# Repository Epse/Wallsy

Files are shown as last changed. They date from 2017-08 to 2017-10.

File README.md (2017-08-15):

# Wallsy
Firmware for a hacked Disney U-Control Wall-e

## What the frig is this?
Me and someone without a github replaced the logic board in a U-Control Wall-e with a [Teensy LC](https://www.pjrc.com/teensy/teensyLC.html).
We added a distance sensor (a Sharp optical ridiculously expensive one since the Chinese ultrasonic cheap ones wouldn't arrive in time)
and a yellow LED in the middle of the sun on Wall-e's 'display'.

## Why would you do that?
It's fun!

## How do I use this?
Get a Teensy, wire it up, modify the `#define`'s in the `main.ino` file and upload to the Teensy.
That is, if your Arduino IDE has the [Teensy libraries](https://www.pjrc.com/teensy/teensyduino.html) installed.

## What works and what doesn't?
- [ ] motor control
- [x] LED blinking
- [ ] IR control
- [ ] Sounds
- [ ] Distance sensing

Yes, for now you let it run by programming moves...

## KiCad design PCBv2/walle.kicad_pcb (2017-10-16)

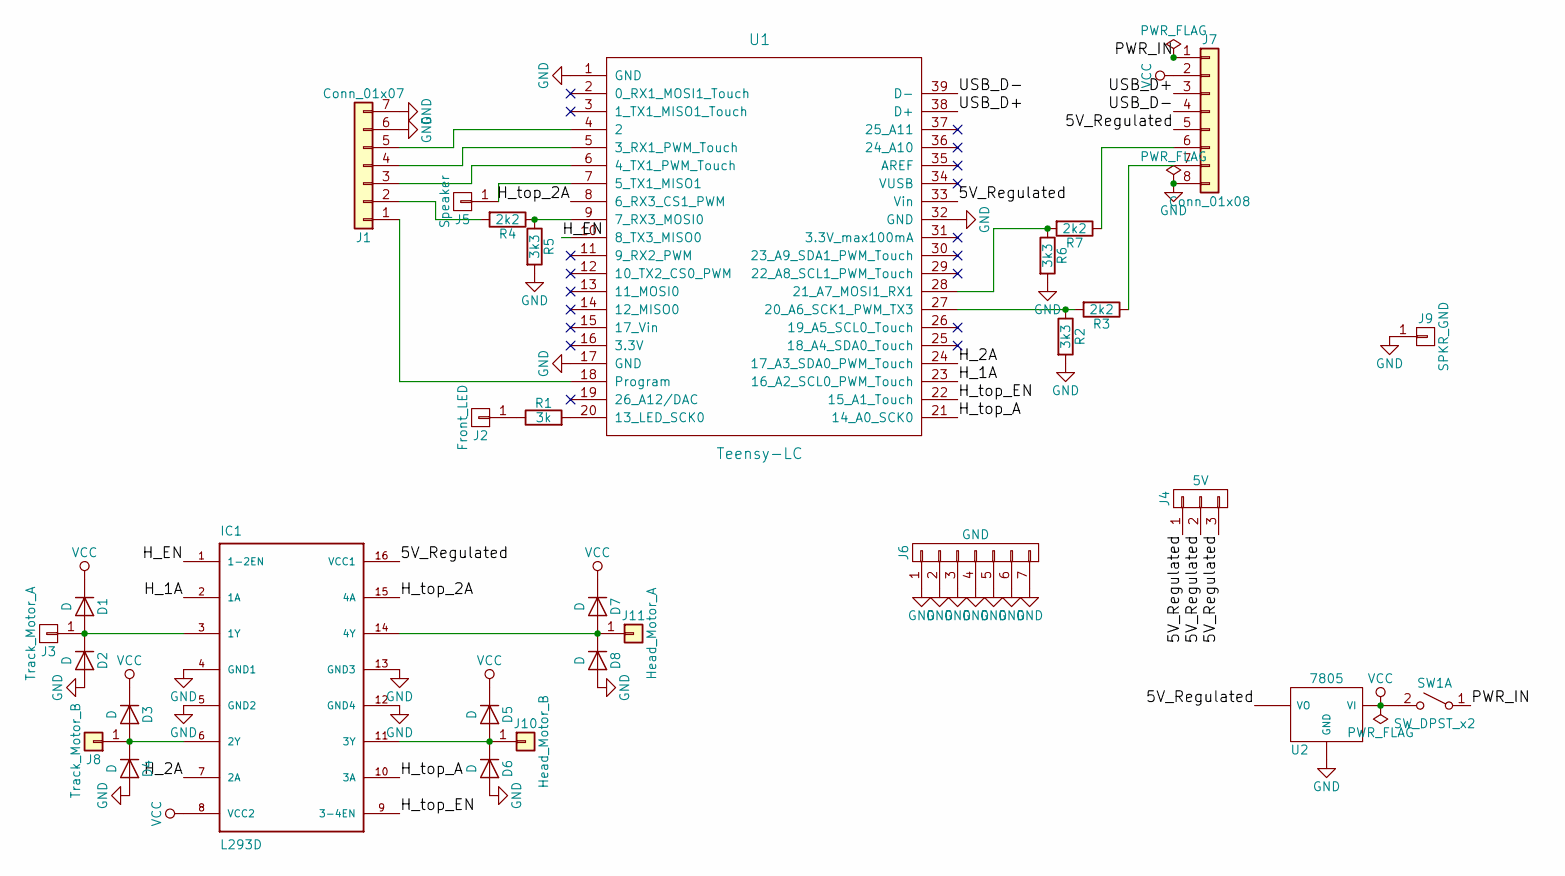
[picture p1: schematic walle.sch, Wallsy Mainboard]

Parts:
D1, D2, D3, D4, D5, D6, D7, D8: D; D_A-405_P2.54mm_Vertical_AnodeUp
IC1: L293D; DIL16
J1: Conn_01x07; Pin_Header_Straight_1x07_Pitch2.54mm
J2: Front_LED; Pin_Header_Straight_1x01_Pitch2.54mm
J3: Track_Motor_A; Pin_Header_Straight_1x01_Pitch2.54mm
J4: 5V; Pin_Header_Straight_1x03_Pitch2.54mm
J5: Speaker; Pin_Header_Straight_1x01_Pitch2.54mm
J6: GND; Pin_Header_Straight_1x07_Pitch2.54mm
J7: Conn_01x08; Pin_Header_Straight_1x08_Pitch2.54mm
J8: Track_Motor_B; Pin_Header_Straight_1x01_Pitch2.54mm
J9: SPKR_GND; Pin_Header_Straight_1x01_Pitch2.54mm
J10: Head_Motor_B; Pin_Header_Straight_1x01_Pitch2.54mm
J11: Head_Motor_A; Pin_Header_Straight_1x01_Pitch2.54mm
R1: 3k; R_Axial_DIN0204_L3.6mm_D1.6mm_P1.90mm_Vertical
R2, R5, R6: 3k3; R_Axial_DIN0204_L3.6mm_D1.6mm_P1.90mm_Vertical
R3, R4, R7: 2k2; R_Axial_DIN0204_L3.6mm_D1.6mm_P1.90mm_Vertical
SW1: SW_DPST_x2; Pin_Header_Straight_1x02_Pitch2.54mm
U1: Teensy-LC; Teensy30_31_32_LC
U2: 7805; TO-220

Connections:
/5V_Regulated: IC1.16 (VCC1), J4.1, J4.2, J4.3, J7.5, U1.33 (Vin), U2.3 (VO)
/H_1A: IC1.2 (1A), U1.23 (16_A2_SCL0_PWM_Touch)
/H_2A: IC1.7 (2A), U1.24 (17_A3_SDA0_PWM_Touch)
/H_EN: IC1.1 (1-2EN), U1.10 (8_TX3_MISO0)
/H_top_2A: IC1.15 (4A), U1.8 (6_RX3_CS1_PWM)
/H_top_A: IC1.10 (3A), U1.21 (14_A0_SCK0)
/H_top_EN: IC1.9 (3-4EN), U1.22 (15_A1_Touch)
/PWR_IN: J7.1, SW1.1 (A)
/USB_D+: J7.3, U1.38 (D+)
/USB_D-: J7.4, U1.39 (D-)
GND: D2.2 (A), D4.2 (A), D6.2 (A), D8.2 (A), IC1.4 (GND1), IC1.5 (GND2), IC1.12 (GND4), IC1.13 (GND3), J1.6, J1.7, J6.1, J6.2, J6.3, J6.4, J6.5, J6.6, J6.7, J7.8, J9.1, R2.2, R5.2, R6.2, U1.1 (GND), U1.17 (GND), U1.32 (GND), U2.2 (GND)
unnamed: D1.2 (A), D2.1 (K), IC1.3 (1Y), J3.1
unnamed: D3.2 (A), D4.1 (K), IC1.6 (2Y), J8.1
unnamed: D5.2 (A), D6.1 (K), IC1.11 (3Y), J10.1
unnamed: D7.2 (A), D8.1 (K), IC1.14 (4Y), J11.1
unnamed: J1.1, U1.18 (Program)
unnamed: J1.2, R4.2
unnamed: J1.3, U1.6 (4_TX1_PWM_Touch)
unnamed: J1.4, U1.5 (3_RX1_PWM_Touch)
unnamed: J1.5, U1.4 (2)
unnamed: J2.1, R1.1
unnamed: J5.1, U1.7 (5_TX1_MISO1)
unnamed: J7.6, R7.1
unnamed: J7.7, R3.1
unnamed: R1.2, U1.20 (13_LED_SCK0)
unnamed: R2.1, R3.2, U1.27 (20_A6_SCK1_PWM_TX3)
unnamed: R4.1, R5.1, U1.9 (7_RX3_MOSI0)
unnamed: R6.1, R7.2, U1.28 (21_A7_MOSI1_RX1)
unnamed: SW1.2 (B), U2.1 (VI)
VCC: D1.1 (K), D3.1 (K), D5.1 (K), D7.1 (K), IC1.8 (VCC2), J7.2

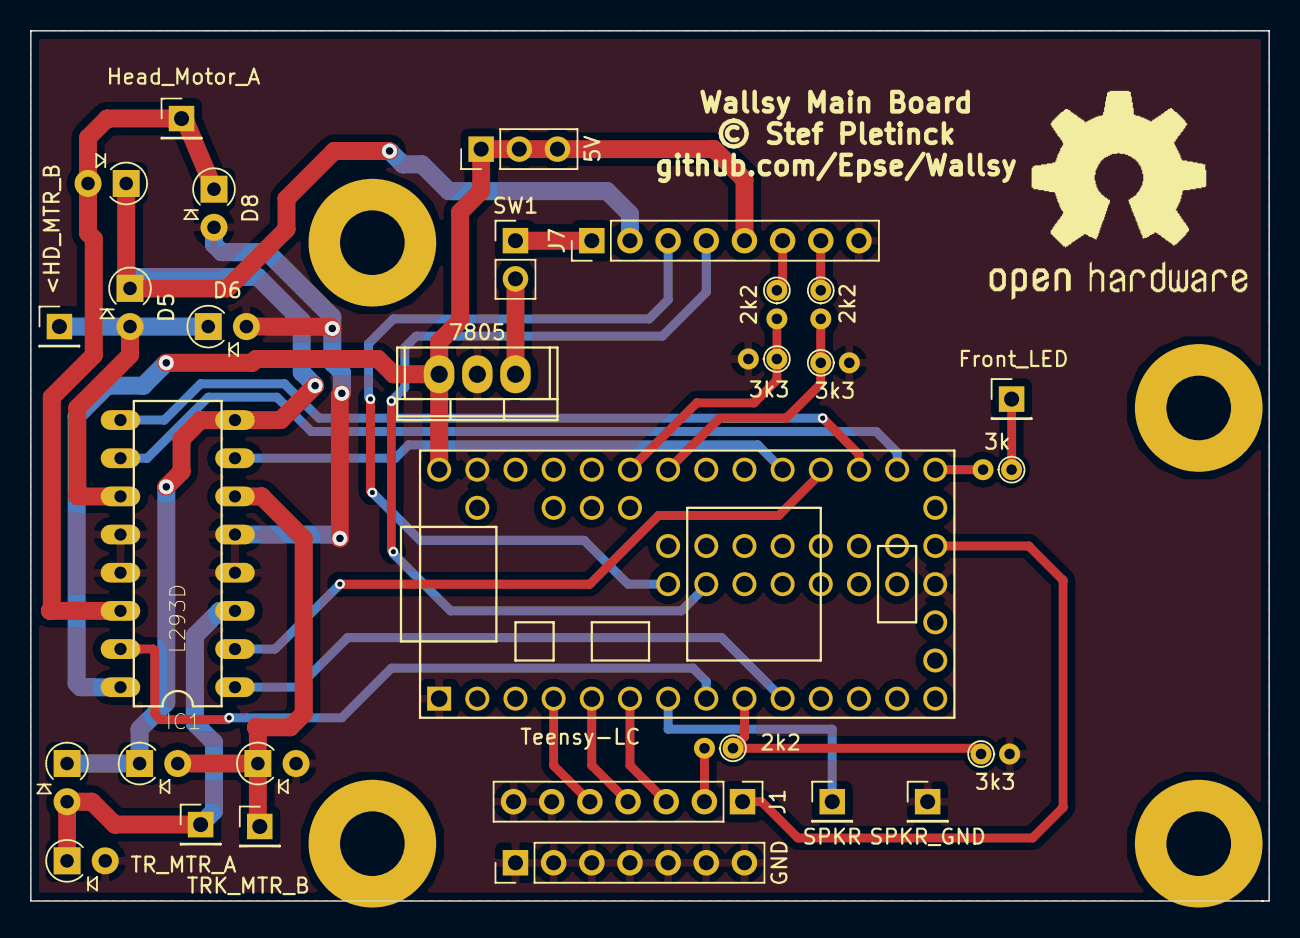
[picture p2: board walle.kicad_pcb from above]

Board: 2 copper layers, 82.4 x 57.9 mm, 30 parts (0 on the bottom side), 30 nets.

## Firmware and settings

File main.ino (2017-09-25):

#include <Arduino.h>
#include "motor.h"
#include "ircodes.h"
#include <IRremote.h>

#define STATUS_LED 13
#define LEFT_EYE_LED 3
#define RIGHT_EYE_LED 4
#define IR_TOP 21
#define IR_REAR 7
#define SPEAKER 5
#define H_BRIDGE_TOP_ENABLE 15
#define H_BRIDGE_TOP_A 14
#define H_BRIDGE_TOP_B 6
#define H_BRIDGE_MVMT_ENABLE 8
#define H_BRIDGE_MVMT_A 17
#define H_BRIDGE_MVMT_B 16
#define DISTANCE_SENS 20

Motor headMotor;
Motor mvmtMotor;

IRrecv irrecvRear(IR_REAR);

unsigned long lastTickMillis = 0;
unsigned long last5Millis = 0;
unsigned long last10Millis = 0;
unsigned long last500Millis = 0;
boolean statusLedValue = LOW;
boolean frontBtnLastKnownValue = false;

void setup() {
  Serial.begin(9600);

  // All my outputs. Tons!!!
  pinMode(STATUS_LED, OUTPUT);
  pinMode(LEFT_EYE_LED, OUTPUT);
  pinMode(RIGHT_EYE_LED, OUTPUT);
  pinMode(SPEAKER, OUTPUT);
  pinMode(DISTANCE_SENS, INPUT);

  // Inputs. Wayyyy less.
  pinMode(IR_TOP, INPUT);
  pinMode(IR_REAR, INPUT);

  irrecvRear.enableIRIn();
  irrecvRear.blink13(true);

  // Own libraries
  // This also initializes the necessary pins to output.
  headMotor.init(H_BRIDGE_TOP_ENABLE, H_BRIDGE_TOP_A, H_BRIDGE_TOP_B);
  mvmtMotor.init(H_BRIDGE_MVMT_ENABLE, H_BRIDGE_MVMT_A, H_BRIDGE_MVMT_B);
  mvmtMotor.enable();

  // Set up some eyes
  analogWrite(LEFT_EYE_LED, 128);
  analogWrite(RIGHT_EYE_LED, 128);
}

// Is called as fast as possible with the delta the millisecond difference since last call.
// WARNING: the delta can be 0!
void tickDispatch(unsigned long delta) {
  lastTickMillis = millis();

  boolean motorShouldTurn = false;
  boolean eyesShouldLight = false;

  decode_results results;
  if (irrecvRear.decode(&results)) {
    if (results.value == IRR_Turn) {
      mvmtMotor.backwards();
      motorShouldTurn = true;
    }

    if (results.value == IRR_Forwards) {
      mvmtMotor.forwards();
      motorShouldTurn = true;
    }

    if (results.value == IRR_Eyes) {
      analogWrite(LEFT_EYE_LED, 400);
      analogWrite(RIGHT_EYE_LED, 400);
      eyesShouldLight = true;
    }

    irrecvRear.resume(); // Receive the next value
  }

  if (!motorShouldTurn) {
    mvmtMotor.stop();
  }
  if (!eyesShouldLight) {
    analogWrite(LEFT_EYE_LED, 128);
    analogWrite(RIGHT_EYE_LED, 128);
  }
}

void fiveMillisDispatch(unsigned long delta) {
  // placeholder
  last5Millis = millis();
}

void tenMillisDispatch(unsigned long delta) {
  //placeholder
  last10Millis = millis();
}

void halfSecondDispatch(unsigned long delta) {
  digitalWrite(STATUS_LED, !statusLedValue);
  statusLedValue = !statusLedValue;
  last500Millis = millis();
}

// This is a dispatch function.
// NOTHING should ever by directly here. Everything MUST be in a dispatch function.
void loop() {

  // the delta can't underflow since time travel hasn't been invented yet...
  tickDispatch(millis() - lastTickMillis);

  // This code WILL break after about 50 days due to `millis()` overflowing. Not an issue.
  // Additional dispatches may be added if necessary
  if (millis() >= last5Millis + 5) {
    fiveMillisDispatch(millis() - last5Millis);
  }
  if (millis() >= last10Millis + 10) {
    tenMillisDispatch(millis() - last10Millis);
  }
  if (millis() >= last500Millis + 500) {
    halfSecondDispatch(millis() - last500Millis);
  }
}

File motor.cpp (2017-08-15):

#include "motor.h"
#include <Arduino.h>

void Motor::init(int initEnablePin, int initAPin, int initBPin) {
  enablePin = initEnablePin;
  aPin = initAPin;
  bPin = initBPin;

  pinMode(enablePin, OUTPUT);
  pinMode(aPin, OUTPUT);
  pinMode(bPin, OUTPUT);
}
void Motor::disable() {
  digitalWrite(enablePin, LOW);
}
void Motor::enable() {
  digitalWrite(enablePin, HIGH);
}
void Motor::forwards() {
  digitalWrite(aPin, LOW);
  digitalWrite(bPin, HIGH);
}
void Motor::backwards() {
  digitalWrite(aPin, HIGH);
  digitalWrite(bPin, LOW);
}
void Motor::stop() {
  digitalWrite(aPin, LOW);
  digitalWrite(bPin, LOW);
}

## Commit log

2017-08-04 motor framework
2017-08-04 its been way too long
    [main.ino]
2017-08-30 Placeholder / test feature for the button and the LED\'s
2017-09-23 updates, but it bricked the teensy
2017-09-24 The front button will be wired up to the program pin
2017-09-25 Gave speaker high current pin
2017-09-27 added KiCAD project for PCB
    [walle.kicad_pcb, walle.sch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]
2017-10-09 PCB redesign for 1 h-bridge
    [walle.sch]
2017-10-09 better pcb
2017-10-11 assigned footprints
    [walle.sch]
2017-10-16 final PCB
    [walle.kicad_pcb]

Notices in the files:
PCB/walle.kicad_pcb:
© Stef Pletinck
